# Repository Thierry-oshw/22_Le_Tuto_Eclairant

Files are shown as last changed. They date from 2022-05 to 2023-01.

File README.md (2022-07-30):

# 22_Le_Tuto_Eclairant

 mots clés: tutoriel led rgb éclairage diorama lighting

## Introduction

Les LEDs sont utilisables pour un diorama. Elles présentent comme avantages:
    1. De ne pas chauffer (en tout cas moins qu’une ampoule si ça existe encore).
    2. D’être tellement vulgarisées et diffusées que leur coût est très faible.
    3. De fonctionner sous une faible tension (de l’ordre de 1,2V pour les LEDs classiques et 5V pour les RGBs)

Une LED RGB est la somme de 3 leds (Rouge, Verte, Bleue = Red Green Blue) pilotées par une petite puce qui va recevoir des instructions par une patte et les retransmettre par une autre pour la LED RGB suivante. Ce point va être détaillé par la suite.

Petite photo de famille :

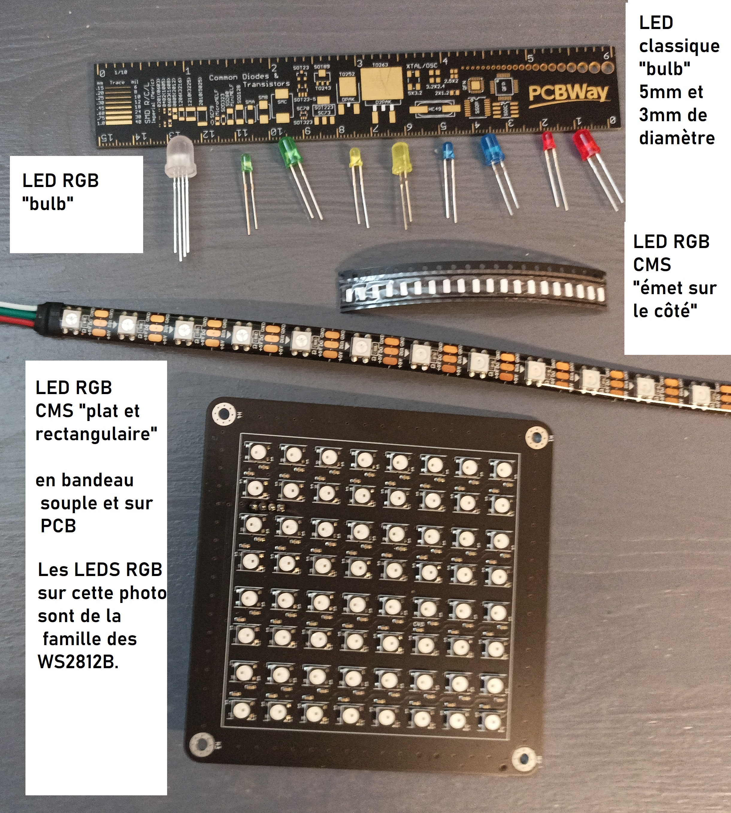
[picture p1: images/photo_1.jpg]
Photo de famille Plusieurs LEDS


En gros, LED classique = 2 pattes, LED RGB = 4 pattes.
Il y a aussi des LEDs classiques bicolores (il y a deux LEDs de couleurs différentes dans le même bulb). Mais je ne vais pas approfondir ce sujet là.

## Pilotage d’une LED classique

Il faut alimenter la LED classique avec une tension à ses bornes de 1,2V en général, et contrôler le courant qui y circule pour qu’il soit de l’ordre de 10mA (entre 5 et 20mA).
Plus le courant est fort, plus la luminosité est forte.
Pour obtenir ces conditions, le plus simple est de relier la LED classique à une source de tension via une résistance qui va limiter le courant et faire chuter la tension.

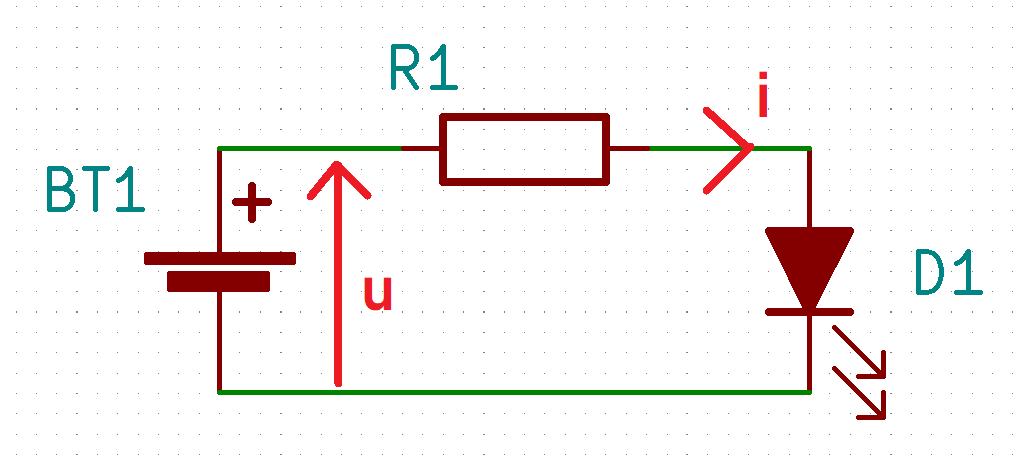
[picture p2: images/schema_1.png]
schema polarisation LED Polarisation d'une LED


Et en gros, pour ceux qui s’en souvienne : u = R1 * i + u(diode)
U(diode) vaut approximativement 1,2V. Si i vaut 5mA, il faut les couples suivants tension u et résistance R1 (je suis sympa, je vous fais un tableau avec des valeurs normalisées).

|u|i|
|-|:-|
|1,5V (pile AAA cylindrique par exemple)|68 Ohms|
|3,3V|470 Ohms|
|5V|820 Ohms|

Les résistances devront avoir un boîtier permettant de dissiper au moins 50mW.
ATTENTION : toujours mettre une résistance sinon ça va mal finir pour la LED. (il y a une façon de faire pour ne pas mettre de résistance mais il faut alors piloter la LED en courant, c’est pas simple).

## Pilotage LED RGB

Il y a plusieurs fabricants de LED RGBs avec bien sûr des différences. Je sais faire fonctionner des LEDs WS2812B (et apparentés). Donc je vous parle de celles-ci.

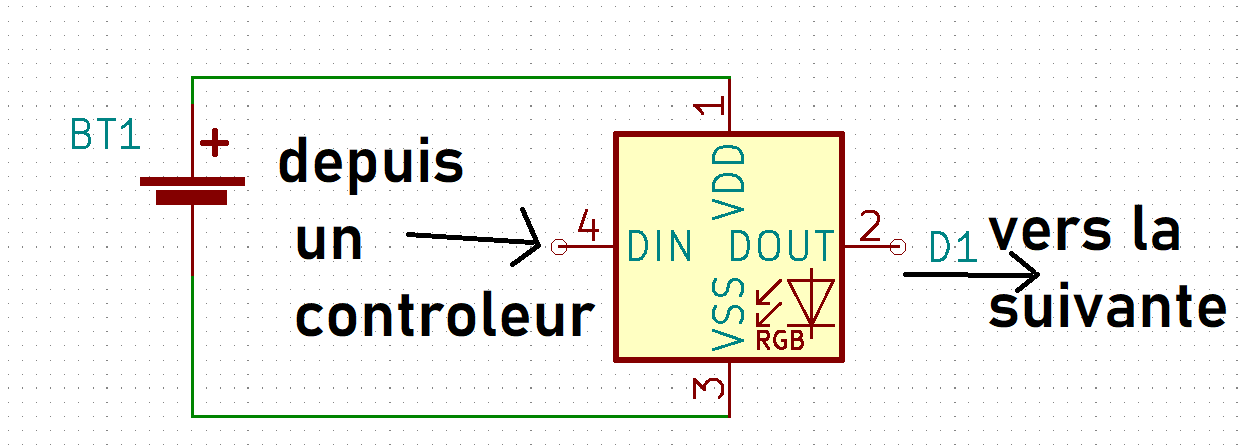
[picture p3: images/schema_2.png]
schema pilotage LED RGB Pilotage LED RGB


Là, la LED a besoin d’une tension 5V sur les pattes 1 (VDD au plus) et 3 (VSS au moins).
La patte DIN reçoit les ordres pour les 3 couleurs pour elle-même ou la suivante via sa patte DOUT.
Les LEDS sont à la queue-leu-leu (daisy chain en anglais).

Une méthode pour les piloter est alors d’utiliser par exemple une carte Arduino Nano avec 3 potentiomètres par exemple :

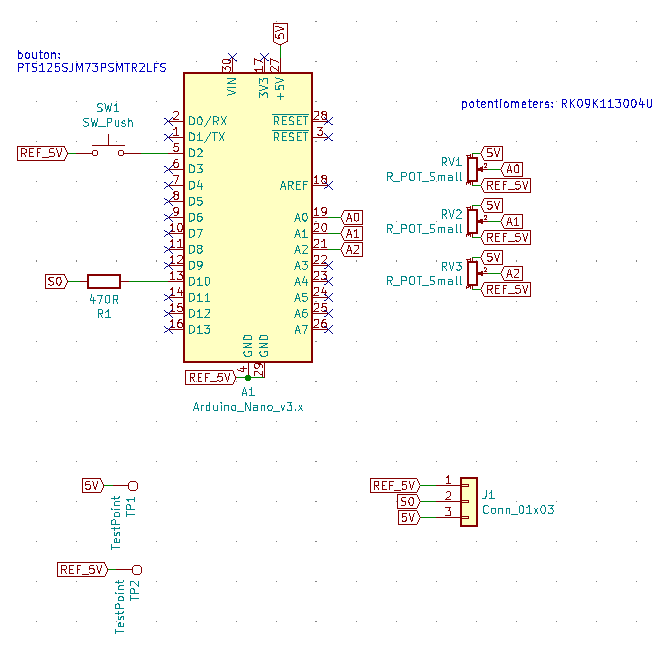
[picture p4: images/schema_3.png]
schema arduino nano Schema arduino nano


Et on utilise le bouton pour régler l'intensité lumineuse.

Les potentiomètres sont dédiées chacun à l'intensité d'une couleur.

La brillance de l'ensemble est réglée par un bouton. Un appui long fait augmenter la valeur jusqu'à un max et retombe à zéro.

Le code arduino est dans le répertoire: Le_Tuto_Eclairant_SW de ce projet.
J'ai utilisé Visual Studio Code avec platform IO. Vous pouvez utilisez à la place l'IDE arduino, vous avez juste à recopier le fichier main dans:
\Le_Tuto_Eclairant_SW\Le_Tuto_Eclairant_SW\src\main.cpp
et le renommer en .ino ou le coller dans un projet Arduino.

Le code est très simple. (Je n'ai même pas mis de debounce sur le bouton..)

Le projet kicad est dans le répertoire: Le_Tuto_Eclairant_HW.
J'utilise encore Kicad version 5, j'ai pas encore migré.

Les fichiers pour la fabrication du PCB sont dans le répertoire: Le_Tuto_Eclairant_HW\dossier_fabrication
Ils sont prêts pour être fabriqué chez JLCPCB.COM. (C'est un exemple).

Quelques photos du résultat:

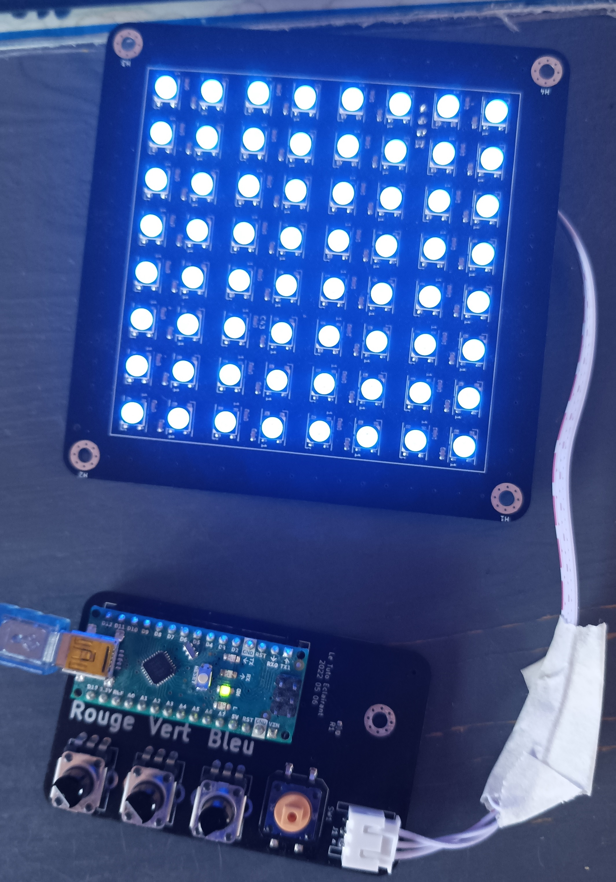
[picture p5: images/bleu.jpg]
bleu

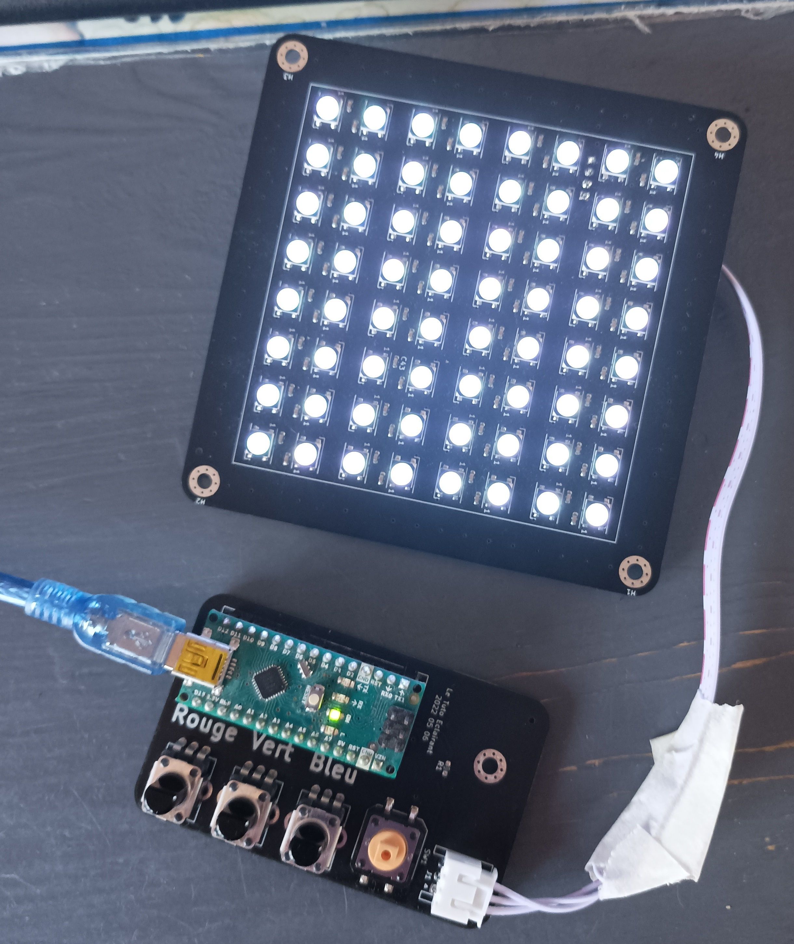
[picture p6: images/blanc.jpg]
blanc

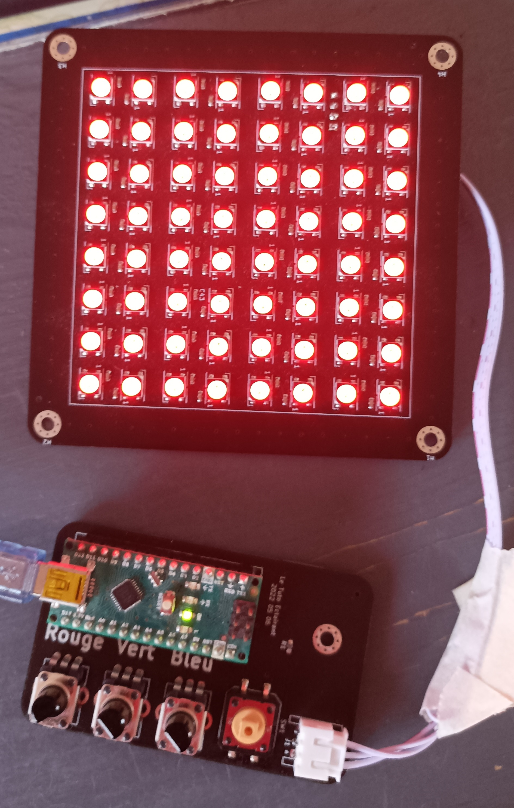
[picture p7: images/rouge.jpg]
rouge

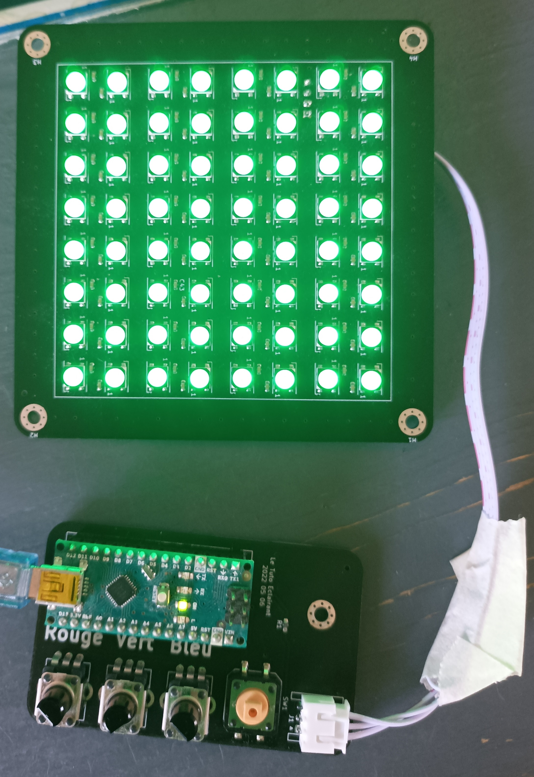
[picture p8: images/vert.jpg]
vert


En espérant que cela puisse vous permettre de réaliser un diorama avec la lumière qui vous plait.

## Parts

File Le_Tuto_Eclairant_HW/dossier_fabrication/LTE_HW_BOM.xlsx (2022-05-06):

Comment | Designator | Footprint | LCSC Part #（optional）
JST_XH_S3B | J1 | JST_XH_S3B | C18428
470R | R1 | R_0603 | C23179
Push button | SW1 | button | C411882
Pot Alps RK09K | RV1,RV2,RV3 | potentiometer | C202382

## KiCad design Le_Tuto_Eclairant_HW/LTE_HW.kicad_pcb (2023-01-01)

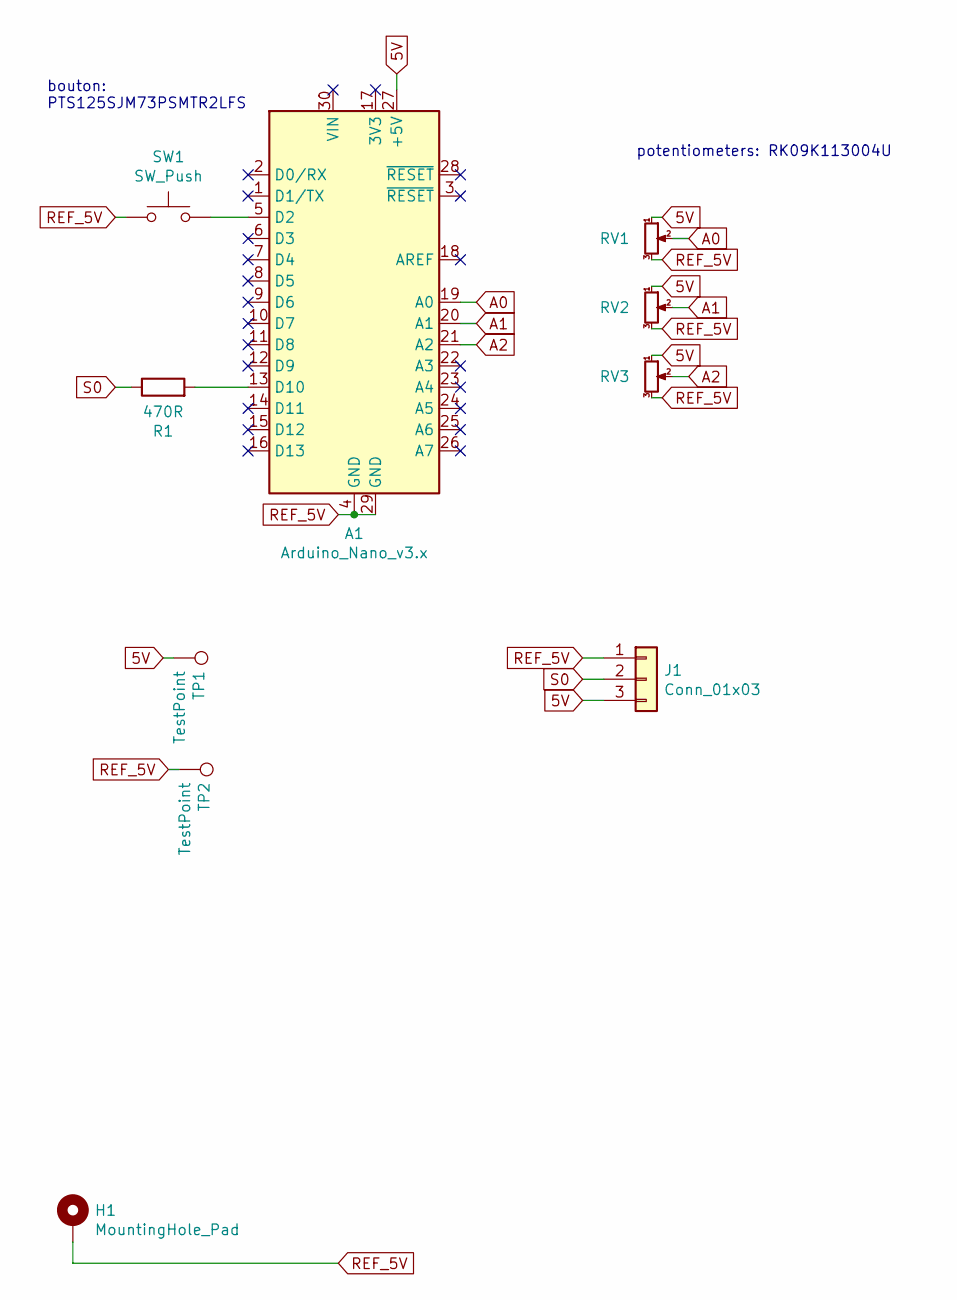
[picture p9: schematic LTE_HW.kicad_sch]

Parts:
A1: Arduino_Nano_v3.x; Arduino_Nano
H1: MountingHole_Pad; MountingHole_3.2mm_M3_Pad_Via
J1: Conn_01x03; JST_XH_S3B-XH-A_1x03_P2.50mm_Horizontal
R1: 470R; R_0603_1608Metric_Pad1.05x0.95mm_HandSolder
RV1, RV2, RV3: R_Potentiometer_Small; Potentiometer_Alps_RK09K_Single_Vertical
SW1: SW_Push; SW_Push_1P1T_NO_CK_PTS125Sx43PSMTR
TP1, TP2: TestPoint; PinHeader_1x01_P2.54mm_Vertical

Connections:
5V: A1.27 (+5V), J1.3, RV1.1, RV2.1, RV3.1, TP1.1
A0: A1.19 (A0), RV1.2
A1: A1.20 (A1), RV2.2
A2: A1.21 (A2), RV3.2
unnamed: A1.5 (D2), SW1.2
unnamed: A1.13 (D10), R1.2
REF_5V: A1.4 (GND), A1.29 (GND), H1.1, J1.1, RV1.3, RV2.3, RV3.3, SW1.1, TP2.1
S0: J1.2, R1.1

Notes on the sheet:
bouton: PTS125SJM73PSMTR2LFS
potentiometers: RK09K113004U

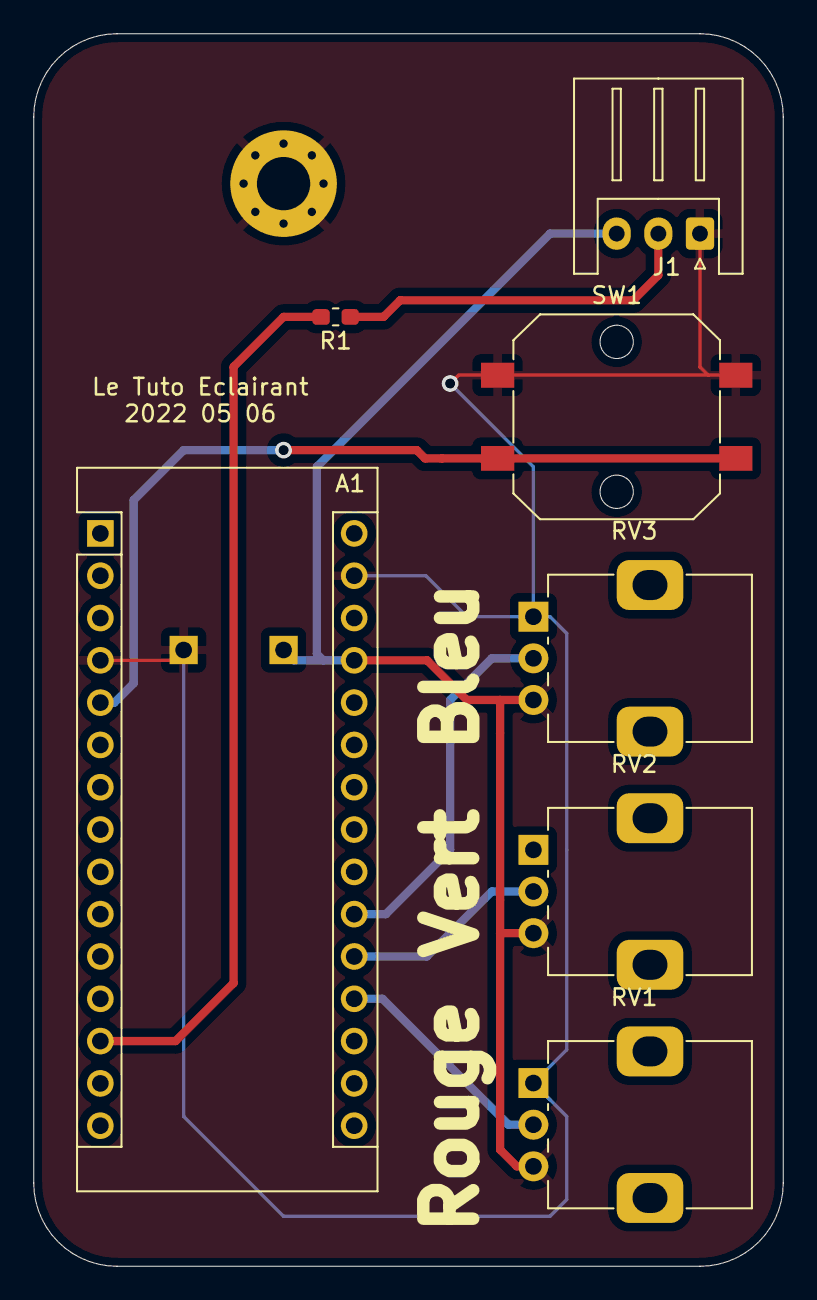
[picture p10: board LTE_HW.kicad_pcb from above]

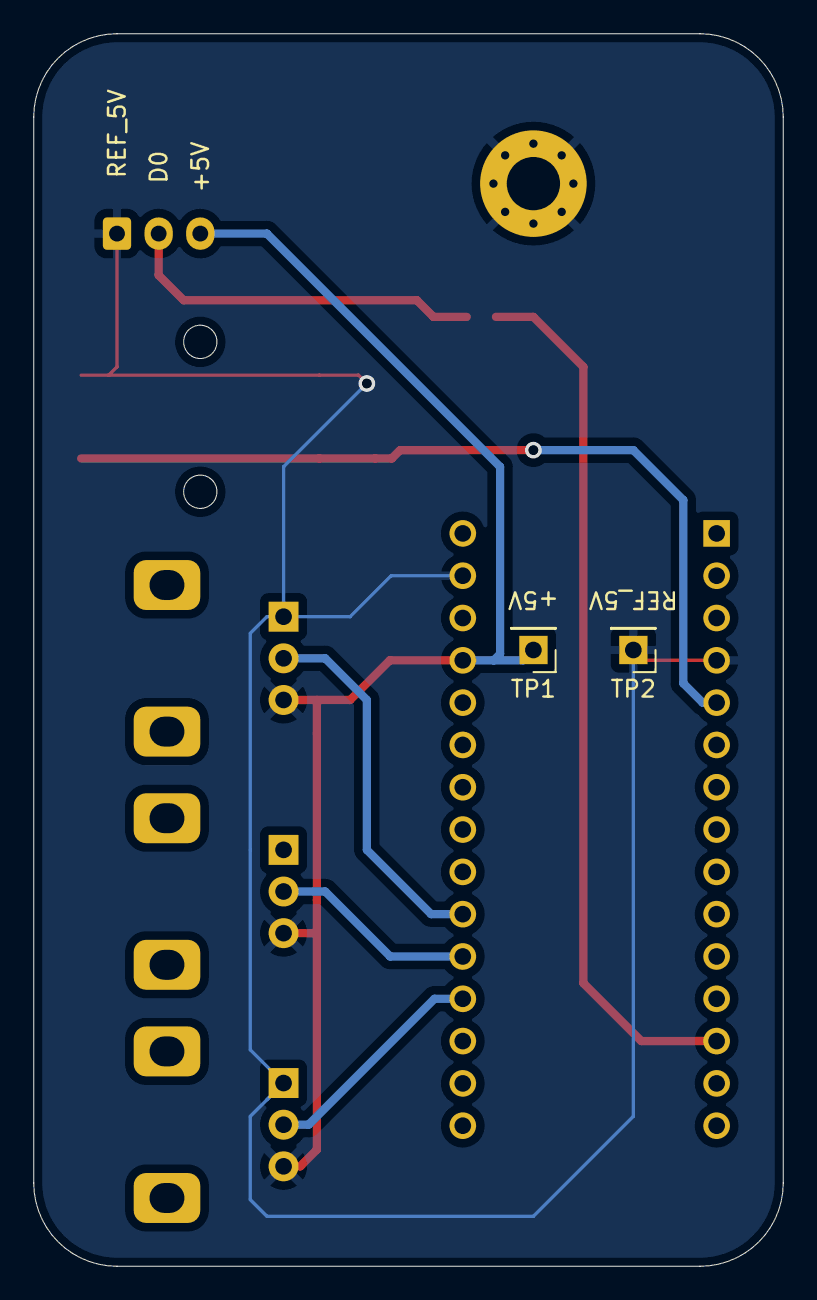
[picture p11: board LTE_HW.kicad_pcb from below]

Board: 2 copper layers, 45.0 x 74.0 mm, 10 parts (2 on the bottom side), 8 nets.

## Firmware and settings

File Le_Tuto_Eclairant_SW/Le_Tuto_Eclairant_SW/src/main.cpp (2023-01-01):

#include <Arduino.h>

#include <FastLED.h>

#define Pot_0 A0
#define Pot_1 A1
#define Pot_2 A2

#define Bouton 2

int index_Pot = 0;
int mes_Pot_0 [8];
int mes_Pot_1 [8];
int mes_Pot_2 [8];

int som_Pot_0 = 0;
int som_Pot_1 = 0;
int som_Pot_2 = 0;

int Brillance = 50;

#define NUM_LEDS 128     
#define DATA_PIN 10
CRGB Leds[NUM_LEDS];

void setup() {
  // put your setup code here, to run once:
    int i = 0;
  for(i = 0 ; i<8; i++)
  {
    mes_Pot_0[i] = 0; 
    mes_Pot_1[i] = 0;
    mes_Pot_2[i] = 0; 

  }

  pinMode(Pot_0, INPUT);
  pinMode(Pot_1, INPUT);
  pinMode(Pot_2, INPUT);
  pinMode(Bouton, INPUT_PULLUP);

  FastLED.addLeds<WS2812B, DATA_PIN, GRB>(Leds, NUM_LEDS);
  FastLED.delay(50);
  FastLED.setBrightness(15);

      // remontée d'info vers PC
  Serial.begin(115200);
  Serial.println("Initialisation faite");
}

void loop() {
  // put your main code here, to run repeatedly:
      // échantillons et somme
    som_Pot_0 -= mes_Pot_0[index_Pot];
    mes_Pot_0[index_Pot] = analogRead(Pot_0);
    som_Pot_0 += mes_Pot_0[index_Pot];

    som_Pot_1 -= mes_Pot_1[index_Pot];
    mes_Pot_1[index_Pot] = analogRead(Pot_1);
    som_Pot_1 += mes_Pot_1[index_Pot];

    som_Pot_2 -= mes_Pot_2[index_Pot];
    mes_Pot_2[index_Pot] = analogRead(Pot_2);
    som_Pot_2 += mes_Pot_2[index_Pot];

    index_Pot++;
    if (index_Pot > 7) {index_Pot = 0;}

    if (digitalRead(Bouton) == 0) {
          Brillance++;
          if (Brillance > 100) {Brillance = 0;}      
       }      

    CRGB couleur = CRGB( (som_Pot_0/32), (som_Pot_1/32), (som_Pot_2/32));
  
    for(int i = 0 ; i<NUM_LEDS; i++)
    {
      Leds[i] = couleur;
    }


//Serial.println(som_Pot_0/32);
//Serial.println("hop");

    FastLED.show();
    //delay(500);
    // Now turn the LED off, then pause
    //Leds[0] = CRGB::Black;
    //FastLED.show();
    //delay(500);
 
    //FastLED.delay(500);
    FastLED.delay(50);
    
    FastLED.setBrightness(Brillance);
 
}

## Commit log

2022-05-06 init and done
    [LTE_HW-B_Cu.gbr, LTE_HW-B_Fab.gbr, LTE_HW-B_Mask.gbr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]
2022-05-06 suppression H2 à H3
    [LTE_HW.kicad_pcb, LTE_HW.sch]
2022-05-06 coché option "monté en surface"
    pour apparition dans fichier position
    [LTE_HW.kicad_pcb]
2022-05-06 coché option pour J1
    pour apparaitre dans fichier de placement
    [LTE_HW.kicad_pcb]
2022-05-06 dossier fabrication
    [LTE_HW_BOM.xlsx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]
2023-01-01 passage à kicad 6
    [LTE_HW.kicad_pcb, LTE_HW.kicad_sch, LTE_HW.sch]
